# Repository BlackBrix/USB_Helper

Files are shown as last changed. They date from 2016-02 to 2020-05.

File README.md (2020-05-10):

# USB_Helper
### A USB switch that enables you to switch the 4 lines (data and power) individually ON or OFF
----
A very useful device not only for makers.  
The four lines 5V,GND,D+,D- can be individually switched ON or OFF (connected or disconnected).  
Look at the pictures, it's pretty self-explanatory...  

### Usecase 1:
Charging (or power supplying) a device (e.g. your mobile / mp3-player / camera) with an "unknown" PC or your companies PC.  
You don't know if this PC "scans" all your private and confidential data,  
you don't know if this PC is "infected" with some virus or malware !  
**Simply switch off the 2 data-lines (D+ and D-) on the USB-Helper and you are protected.**  

### Usecase 2:
Sometimes you want to communicate with a device but without connecting the 5V from the PC.  
(quite often the 5V-supply from a PC is very noisy, with voltage spikes or some humming occurs...)  
**examples:**  
 -- communicating with a microcontroller system that has it's own power supply (3.3V / or own 5V-System)  
 -- using USB audio systems (e.g. external D/A-converter) with own power supply without "injecting" noises and humming from the PC.  
**Simply switch off the 5V-line on the USB-Helper and you are ready to go.**  
(in some scenarios even the GND switch can be disconnected as well, you have to try)  

### Specifications:
* the four lines 5V,GND,D+,D- can be individually switched ON or OFF (connected or disconnected)
* USB "Type A" male and female connector
* compatible with USB 1.0 / USB 2.0 devices
* compatible with Low Speed [1,5 Mbit/s], Full Speed [12 Mbit/s], Hi-Speed [480 Mbit/s] devices
* the (special heavy-duty) DIP-switch is capable of switching and holding a load of 500mA
* a transparent heat shrink tube is used as protection against short circuit
* dimensions assembled: 50,9mm x 16,6mm x 12,5mm (length x width x height)
* dimensions bare PCB only: 30,1mm x 16,6mm x 1,7mm (length x width x height)  
  
----

get one ->  
  

----

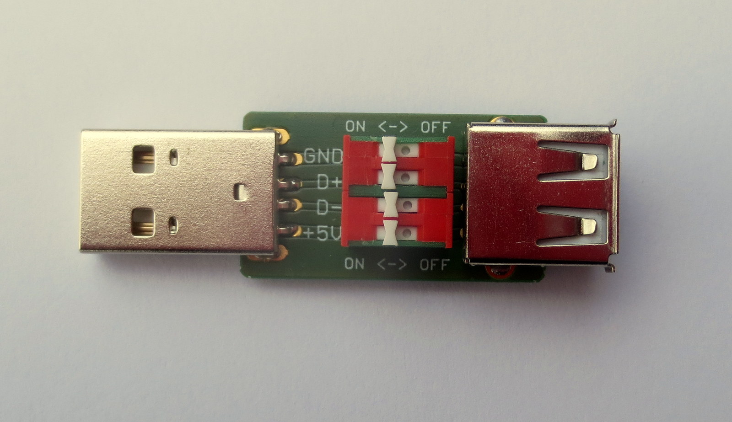
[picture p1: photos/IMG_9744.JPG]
USB Helper

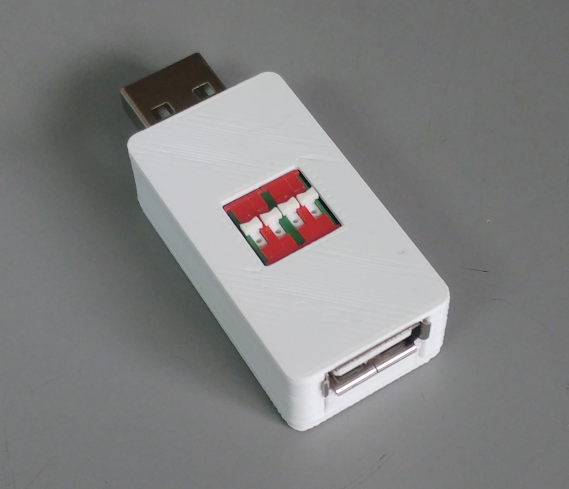
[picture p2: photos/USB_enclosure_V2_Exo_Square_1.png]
USB Helper Enclosure


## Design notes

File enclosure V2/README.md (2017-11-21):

This enclosure ("V2") has been designed and manufactured by  
Dave from [Exo_Square] --> [https://www.tindie.com/stores/Exo_Square](https://www.tindie.com/stores/Exo_Square)

Test

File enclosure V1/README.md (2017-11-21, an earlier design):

This enclosure has been designed and manufactured by  
Garrett Bartley [Wgb.Me] --> https://www.tindie.com/stores/wgbartley 

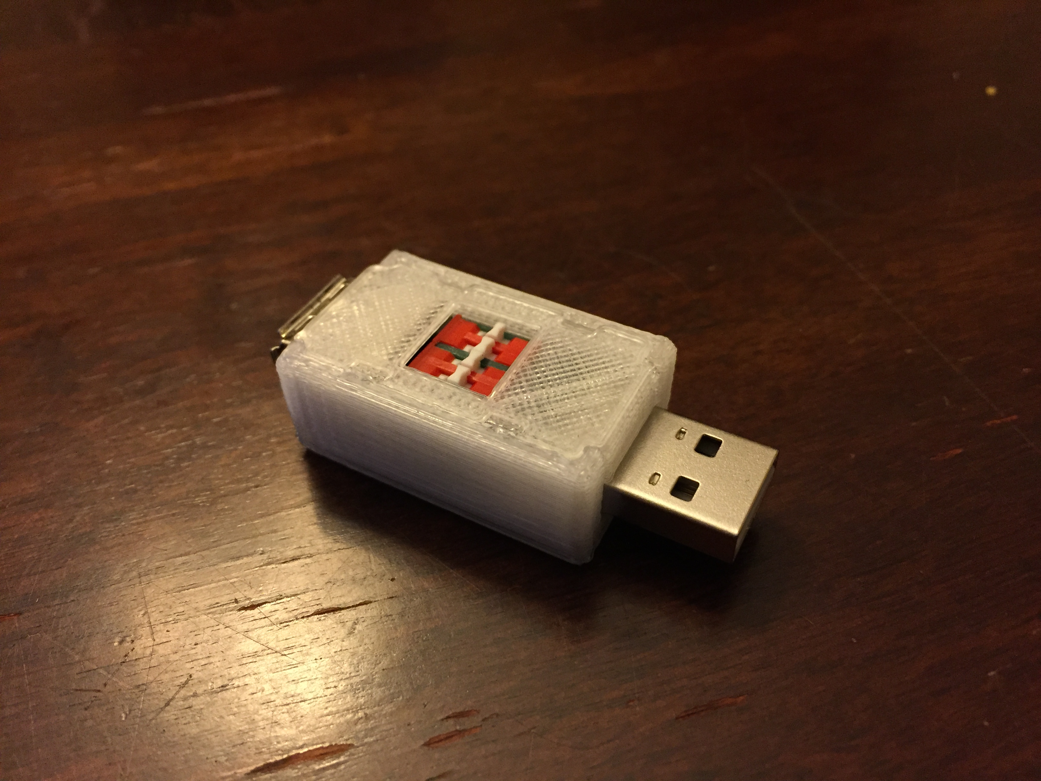
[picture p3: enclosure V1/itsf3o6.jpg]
USB Helper Enclosure


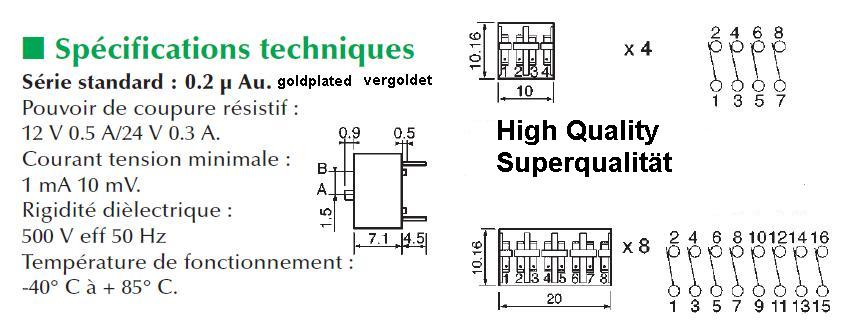
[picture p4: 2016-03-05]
hardware/Datasheets/Data_DIP_Switch.jpg

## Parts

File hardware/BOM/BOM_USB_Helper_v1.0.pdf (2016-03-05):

### BOM: USB-Helper v1.0

Pos. | Qty. | Description | Supplier | Supplier Part No. | Manufacturer | Manufacturer Part No. | datasheet link
01 | 1 | PCB | Eurocircuits.com | P022457 | Eurocircuits | P022457 | -/-
02 | 1 | DIP-Switch 4P. 500mA | ebay.com | 271703386418 | SECME / eao.com | 09.22000.03 | https://github.com/BlackBrix/USB_Helper/blob/master/hardware/Datasheets/SECME.09.22000.03.4-fach.THT.von.ebay.pdf
03 | 1 | USB panel plug, series A | Reichelt.com | USB AWF | China (?) | -/- | https://github.com/BlackBrix/USB_Helper/blob/master/hardware/Datasheets/USB_A_Stecker_THT.Reichelt.USB.AWF.pdf
04 | 1 | USB panel socket, series A | Reichelt.com | USB AW | Assmann | A-USBS-A | https://github.com/BlackBrix/USB_Helper/raw/master/hardware/Datasheets/USB_A_Buchse_THT.Reichelt.USB.AW.pdf
05 | 0,035m | Heat-shrink tube transparent | Reichelt.com | SDB 19,1 TR | -/- | -/- | -/-

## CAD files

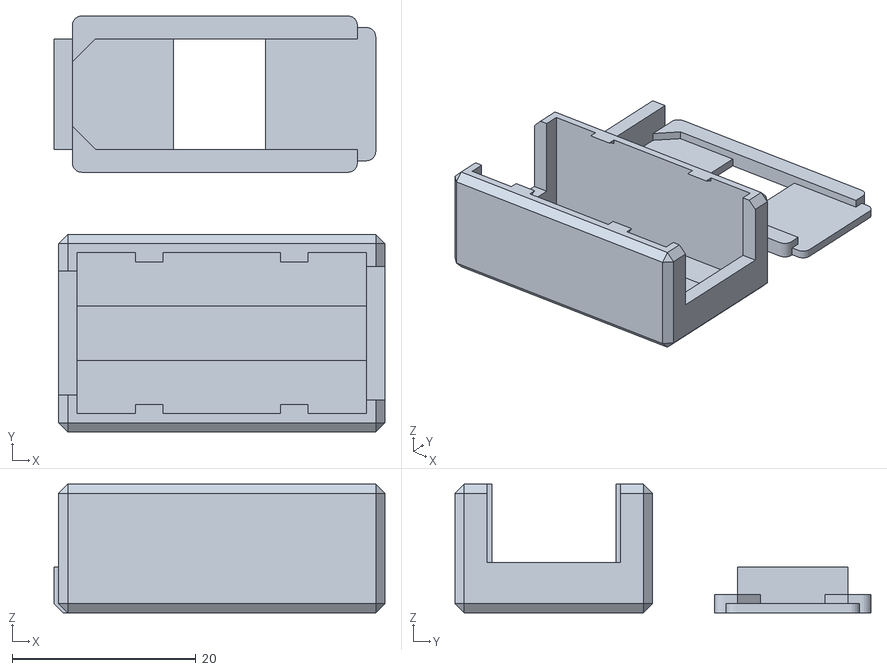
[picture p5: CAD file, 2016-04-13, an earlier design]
enclosure V1/usb-helper-v2.stl
36.0 x 45.3 x 14.0

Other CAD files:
enclosure V1/usb-helper-v2.skp

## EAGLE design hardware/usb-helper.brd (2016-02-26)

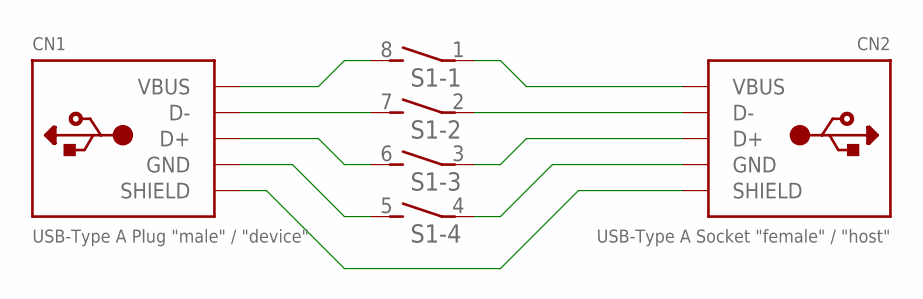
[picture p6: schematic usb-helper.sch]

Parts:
CN1: USB-Type A Plug "male" / "device"; USB_PLUG_A_THT_AWF
CN2: USB-Type A Socket "female" / "host"; USB_SOCKET_A_THT_AW
S1: DIP04S_SECME; DIP_04_SECME_THT

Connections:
D+: CN1.D+, S1.6 (2)
D+_S: CN2.D+, S1.3 (1)
D-: CN1.D-, S1.7 (2)
D-_S: CN2.D-, S1.2 (1)
GND: CN1.GND, S1.5 (2)
GND_S: CN2.GND, S1.4 (1)
SHIELD: CN1.SHIELD1 (SHIELD), CN1.SHIELD2 (SHIELD), CN2.S1 (SHIELD), CN2.S2 (SHIELD)
VBUS: CN1.VBUS, S1.8 (2)
VBUS_S: CN2.VBUS, S1.1

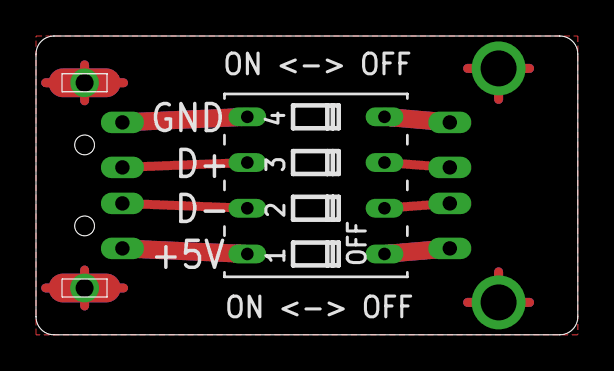
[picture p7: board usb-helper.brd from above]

Board: 2 copper layers, 30.1 x 16.6 mm, 3 parts (0 on the bottom side), 9 nets.

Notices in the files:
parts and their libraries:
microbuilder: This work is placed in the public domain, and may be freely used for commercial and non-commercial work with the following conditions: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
